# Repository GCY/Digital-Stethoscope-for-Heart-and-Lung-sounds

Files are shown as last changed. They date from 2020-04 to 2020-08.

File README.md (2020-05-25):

# Digital-Stethoscope-for-Heart-and-Lung-sounds

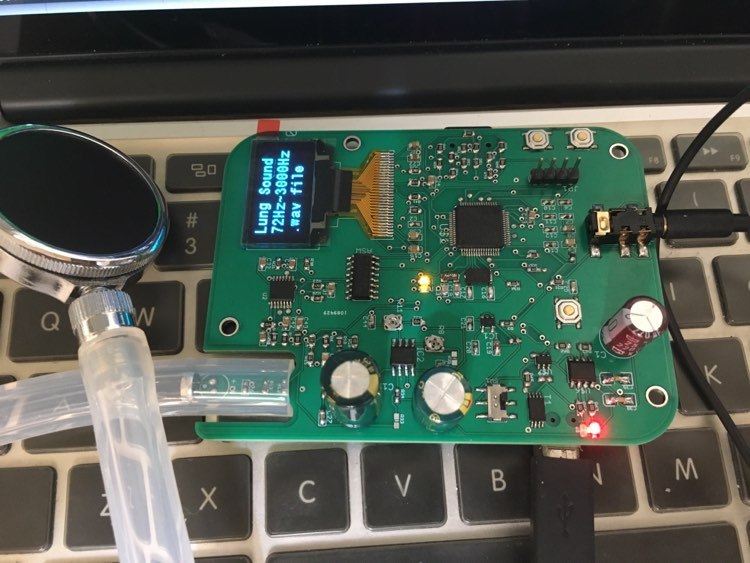
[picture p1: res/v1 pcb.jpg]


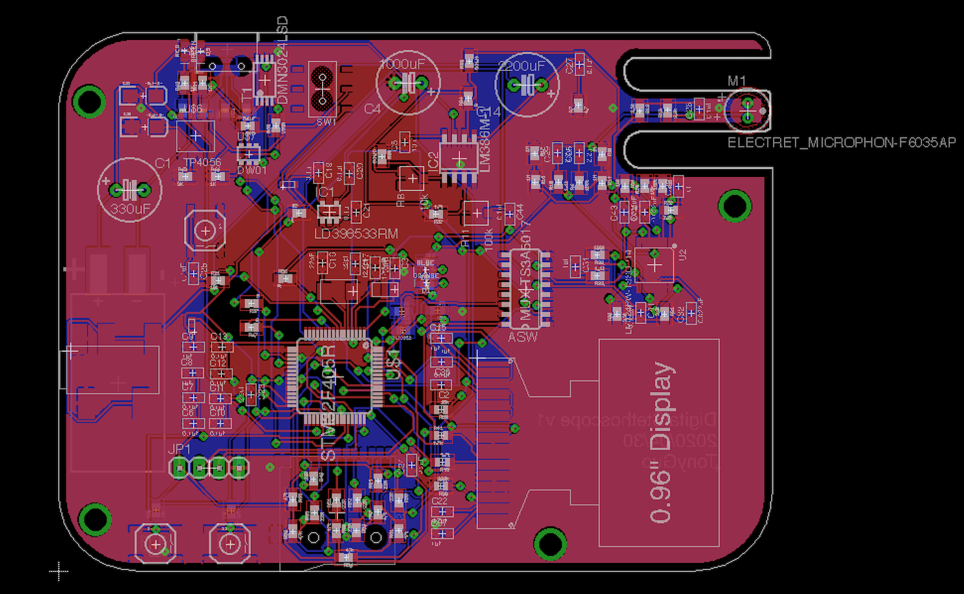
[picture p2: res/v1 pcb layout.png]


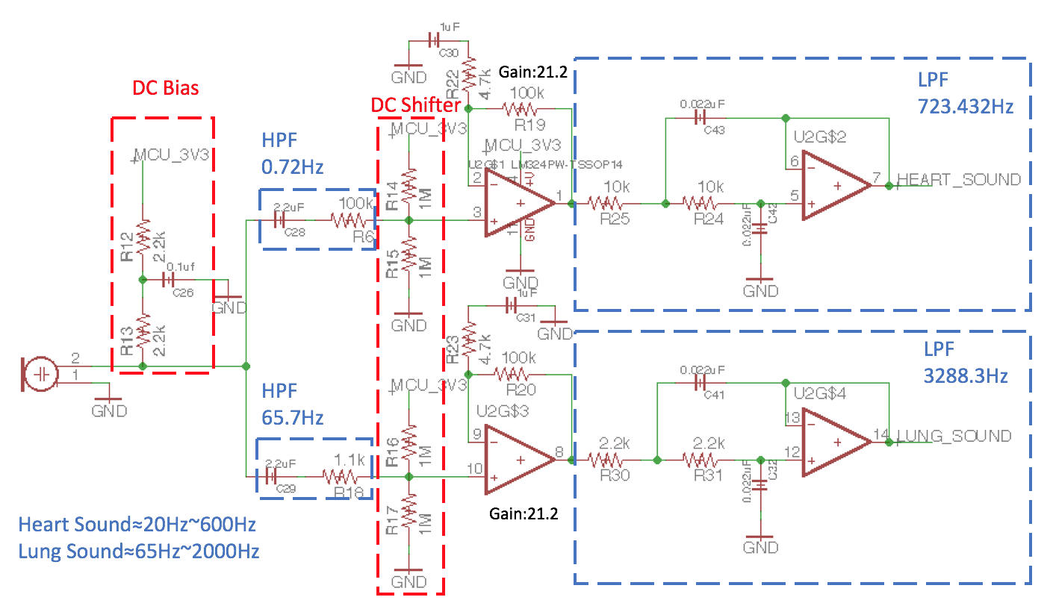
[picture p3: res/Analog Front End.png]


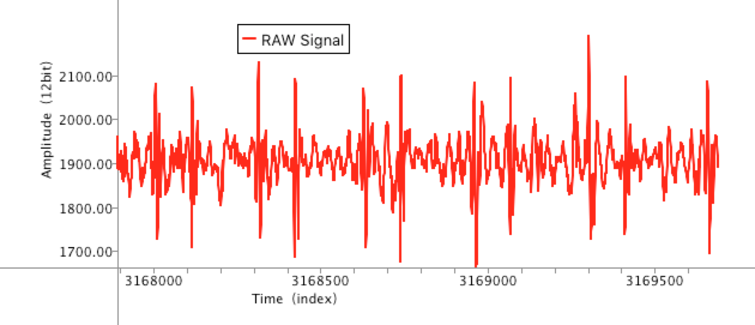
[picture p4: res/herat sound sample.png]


## Features
- [x] Headphone(3.5mm) mode for auscultation
- [ ] Heart and Lung Sounds mode switch 
- [ ] Software Filter
  - [ ] Infinite Impulse Response(IIR)
  - [ ] Finite Impulse Response(FIR)  
- [ ] Algorithm
  - [ ] Heart Sound and Lung Sound separation algorithms
- [ ] PC-Host Analysis 
  - [ ] Fast Furious Transform(FFT) amplitude spectrum
  - [ ] Mel Spectrogram
- [ ] SD card operate
  - [ ] Heart and Lung Sounds recoed .wav file to SD card
  - [ ] Replay sample of disease from SD card

## Reference
- Nersisson, R., & Noel, M. M. (2017). Heart sound and lung sound separation algorithms: a review. Journal of medical engineering & technology, 41(1), 13-21.
- Chowdhury, M. E., Khandakar, A., Alzoubi, K., Mansoor, S., M Tahir, A., Reaz, M. B. I., & Al-Emadi, N. (2019). Real-Time Smart-Digital Stethoscope System for Heart Diseases Monitoring. Sensors, 19(12), 2781.
- [How to Bias an Op-Amp](https://ocw.mit.edu/courses/media-arts-and-sciences/mas-836-sensor-technologies-for-interactive-environments-spring-2011/readings/MITMAS_836S11_read02_bias.pdf)
- [Active High Pass Filter](https://www.electronics-tutorials.ws/filter/filter_6.html) 

LICENSE
-------

MIT License

Copyright (c) 2020 Tony Guo https://github.com/GCY

Permission is hereby granted, free of charge, to any person obtaining a copy
of this software and associated documentation files (the "Software"), to deal
in the Software without restriction, including without limitation the rights
to use, copy, modify, merge, publish, distribute, sublicense, and/or sell
copies of the Software, and to permit persons to whom the Software is
furnished to do so, subject to the following conditions:

The above copyright notice and this permission notice shall be included in all
copies or substantial portions of the Software.

THE SOFTWARE IS PROVIDED "AS IS", WITHOUT WARRANTY OF ANY KIND, EXPRESS OR
IMPLIED, INCLUDING BUT NOT LIMITED TO THE WARRANTIES OF MERCHANTABILITY,
FITNESS FOR A PARTICULAR PURPOSE AND NONINFRINGEMENT. IN NO EVENT SHALL THE
AUTHORS OR COPYRIGHT HOLDERS BE LIABLE FOR ANY CLAIM, DAMAGES OR OTHER
LIABILITY, WHETHER IN AN ACTION OF CONTRACT, TORT OR OTHERWISE, ARISING FROM,
OUT OF OR IN CONNECTION WITH THE SOFTWARE OR THE USE OR OTHER DEALINGS IN THE
SOFTWARE.

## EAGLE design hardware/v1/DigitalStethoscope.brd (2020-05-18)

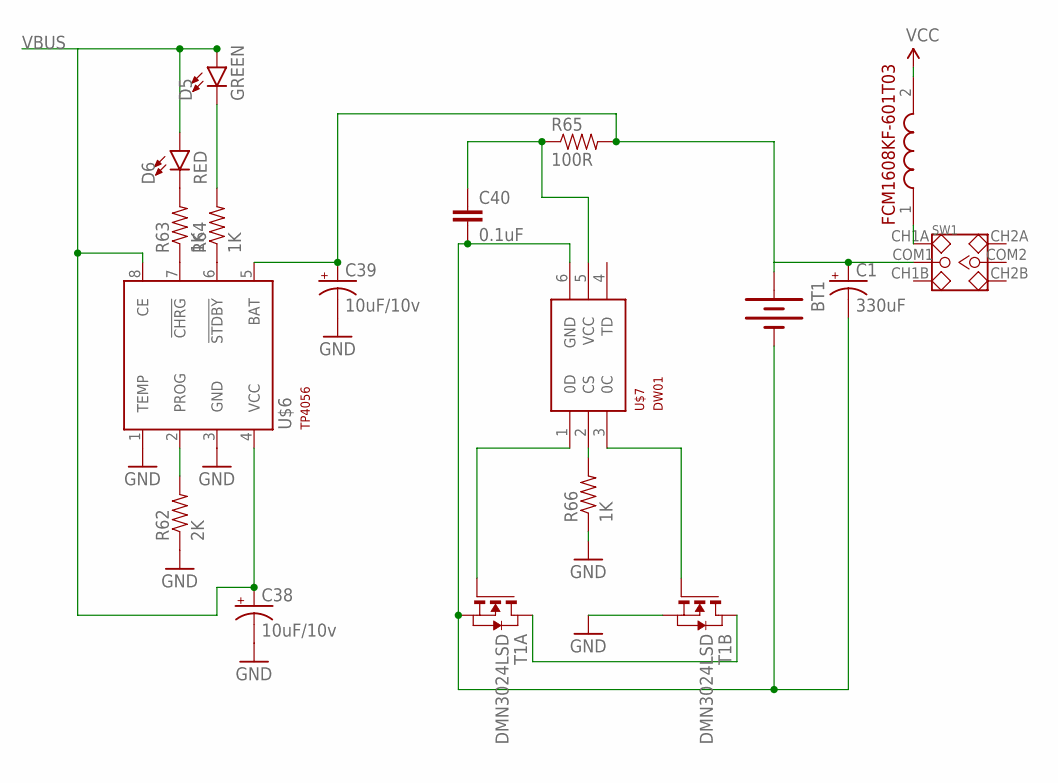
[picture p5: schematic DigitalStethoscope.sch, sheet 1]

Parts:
BT1: BATTERYLIPO-TABS; LIPO-110-TABS
C1: 330uF; E3,5-8
C38, C39: 10uF/10v; EIA3216-KIT
C40: 0.1uF; 0603-CAP
D5: GREEN; LED-0603
D6: RED; LED-0603
R62: 2K; 0603-RES
R63, R64, R66: 1K; 0603-RES
R65: 100R; 0603-RES
SW1: SMD-TOGGLE-SWITCH-2CH(2X3P-7X3.5MM); SW6-2.54-SMD-7.0X3.5X1.5MM
T1: DMN3024LSD; TSSOP-8
U$4: FCM1608KF-601T03
U$6: TP4056; SOT23-8
U$7: DW01; SOT23-6

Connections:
GND: C38.C (-), C39.C (-), R62.1, R66.1, T1.6 (S), T1.7 (S), U$6.1 (TEMP), U$6.3 (GND); also elsewhere on the board
unnamed: BT1.+, C1.+, C39.A (+), R65.2, SW1.COM1, U$6.5 (BAT)
unnamed: R62.2, U$6.2 (PROG)
unnamed: R63.1, U$6.7 (!CHRG)
unnamed: R64.1, U$6.6 (!STDBY)
unnamed: D6.C, R63.2
unnamed: D5.C, R64.2
unnamed: C40.1, R65.1, U$7.5 (VCC)
unnamed: BT1.-, C1.-, C40.2, T1.2 (S), T1.3 (S), U$7.6 (GND)
unnamed: T1.4 (G), U$7.1 (0D)
unnamed: R66.2, U$7.2 (CS)
unnamed: T1.1 (D), T1.8 (D)
unnamed: T1.5 (G), U$7.3 (0C)
unnamed: SW1.CH1A, U$4.1 (1.IN)
VBUS: C38.A (+), D5.A, D6.A, U$6.4 (VCC), U$6.8 (CE); also elsewhere on the board
VCC: U$4.2 (2.OUT); also elsewhere on the board

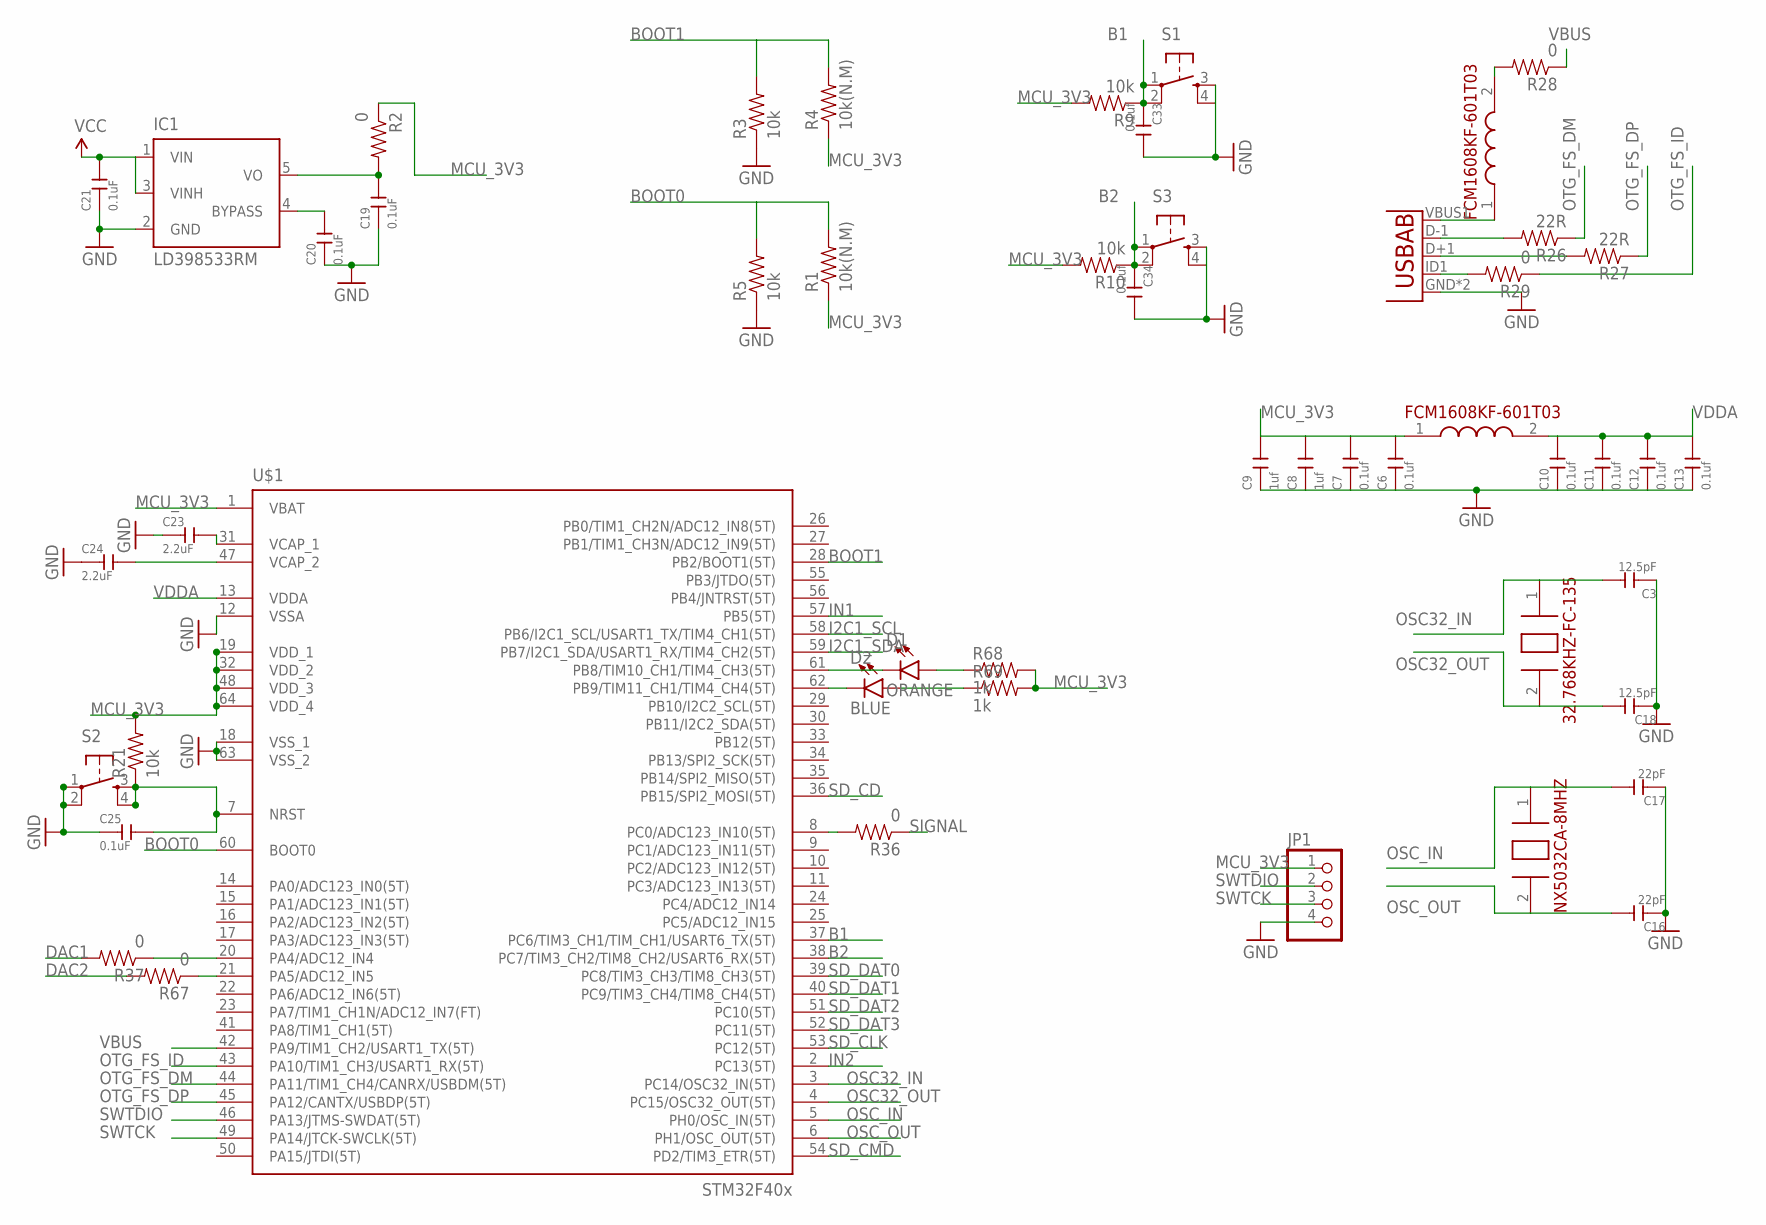
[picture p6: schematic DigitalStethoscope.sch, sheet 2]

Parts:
C3, C18: 12.5pF; C0603
C6, C7, C10, C11, C12, C13, C33, C34: 0.1uf; C0603
C8, C9: 1uf; C0603
C16, C17: 22pF; C0603
C19, C20, C21, C25: 0.1uF; C0603
C23, C24: 2.2uF; C0603
D1: ORANGE; LED-0603
D2: BLUE; LED-0603
IC1: LD398533RM; SOT23-5L
JP1: PINHD-1X4; 1X04
R1, R4: 10k(N.M); 0603
R2, R28, R29, R36, R37, R67: 0; 0603-RES
R3, R5, R9, R10: 10k; 0603
R21: 10k; 0603-RES
R26, R27: 22R; 0603-RES
R68, R69: 1k; 0603-RES
S1, S2, S3: TAC_SWITCHSMD; TACTILE_SWITCH_SMD
U4: USB""; USB-MICRO-SMD
U$1: STM32F405R; TQFP64
U$2: 32.768KHZ-FC-135
U$3, U$5: FCM1608KF-601T03
U$8: NX5032CA-8MHZ

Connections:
B1: C33.1, R9.1, S1.1, S1.2, U$1.37 (PC6/TIM3_CH1/TIM_CH1/USART6_TX(5T))
B2: C34.1, R10.1, S3.1, S3.2, U$1.38 (PC7/TIM3_CH2/TIM8_CH2/USART6_RX(5T))
BOOT0: R1.2, R5.2, U$1.60 (BOOT0)
BOOT1: R3.2, R4.2, U$1.28 (PB2/BOOT1(5T))
DAC1: R37.2; also elsewhere on the board
DAC2: R67.2; also elsewhere on the board
GND: C3.1, C6.1, C7.1, C8.1, C9.1, C10.1, C11.1, C12.1, C13.1, C16.1, C17.1, C18.1, C19.1, C20.1, C21.1, C23.1, C24.1, C25.1, C33.2, C34.2, IC1.2 (GND), JP1.4, R3.1, R5.1, S1.3, S1.4, S2.1, S2.2, S3.3, S3.4, U4.GND, U4.GND1 (GND), U$1.12 (VSSA), U$1.18 (VSS_1), U$1.63 (VSS_2); also elsewhere on the board
I2C1_SCL: U$1.58 (PB6/I2C1_SCL/USART1_TX/TIM4_CH1(5T)); also elsewhere on the board
I2C1_SDA: U$1.59 (PB7/I2C1_SDA/USART1_RX/TIM4_CH2(5T)); also elsewhere on the board
IN1: U$1.57 (PB5(5T)); also elsewhere on the board
IN2: U$1.2 (PC13(5T)); also elsewhere on the board
MCU_3V3: C6.2, C7.2, C8.2, C9.2, JP1.1, R1.1, R2.1, R4.1, R9.2, R10.2, R21.2, R68.2, R69.2, U$1.1 (VBAT), U$1.19 (VDD_1), U$1.32 (VDD_2), U$1.48 (VDD_3), U$1.64 (VDD_4), U$3.1 (1.IN); also elsewhere on the board
unnamed: C20.2, IC1.4 (BYPASS)
unnamed: R36.2, U$1.8 (PC0/ADC123_IN10(5T))
unnamed: R26.2, U4.D-1 (D-)
unnamed: C23.2, U$1.31 (VCAP_1)
unnamed: C24.2, U$1.47 (VCAP_2)
unnamed: R37.1, U$1.20 (PA4/ADC12_IN4)
unnamed: C25.2, R21.1, S2.3, S2.4, U$1.7 (NRST)
unnamed: C19.2, IC1.5 (VO), R2.2
unnamed: R27.2, U4.D+1 (D+)
unnamed: U4.VBUS1 (VBUS), U$5.1 (1.IN)
unnamed: R29.2, U4.ID1 (USBID)
unnamed: R28.2, U$5.2 (2.OUT)
unnamed: R67.1, U$1.21 (PA5/ADC12_IN5)
unnamed: D2.C, U$1.62 (PB9/TIM11_CH1/TIM4_CH4(5T))
unnamed: D1.C, U$1.61 (PB8/TIM10_CH1/TIM4_CH3(5T))
unnamed: D1.A, R68.1
unnamed: D2.A, R69.1
OSC32_IN: C3.2, U$1.3 (PC14/OSC32_IN(5T)), U$2.1 (1.XIN)
OSC32_OUT: C18.2, U$1.4 (PC15/OSC32_OUT(5T)), U$2.2 (2.XIN)
OSC_IN: C17.2, U$1.5 (PH0/OSC_IN(5T)), U$8.1 (1.XIN)
OSC_OUT: C16.2, U$1.6 (PH1/OSC_OUT(5T)), U$8.2 (2.XOUT)
OTG_FS_DM: R26.1, U$1.44 (PA11/TIM1_CH4/CANRX/USBDM(5T))
OTG_FS_DP: R27.1, U$1.45 (PA12/CANTX/USBDP(5T))
OTG_FS_ID: R29.1, U$1.43 (PA10/TIM1_CH3/USART1_RX(5T))
SD_CD: U$1.36 (PB15/SPI2_MOSI(5T)); also elsewhere on the board
SD_CLK: U$1.53 (PC12(5T)); also elsewhere on the board
SD_CMD: U$1.54 (PD2/TIM3_ETR(5T)); also elsewhere on the board
SD_DAT0: U$1.39 (PC8/TIM3_CH3/TIM8_CH3(5T)); also elsewhere on the board
SD_DAT1: U$1.40 (PC9/TIM3_CH4/TIM8_CH4(5T)); also elsewhere on the board
SD_DAT2: U$1.51 (PC10(5T)); also elsewhere on the board
SD_DAT3: U$1.52 (PC11(5T)); also elsewhere on the board
SIGNAL: R36.1; also elsewhere on the board
SWTCK: JP1.3, U$1.49 (PA14/JTCK-SWCLK(5T))
SWTDIO: JP1.2, U$1.46 (PA13/JTMS-SWDAT(5T))
VBUS: R28.1, U$1.42 (PA9/TIM1_CH2/USART1_TX(5T)); also elsewhere on the board
VCC: C21.2, IC1.1 (VIN), IC1.3 (VINH); also elsewhere on the board
VDDA: C10.2, C11.2, C12.2, C13.2, U$1.13 (VDDA), U$3.2 (2.OUT)

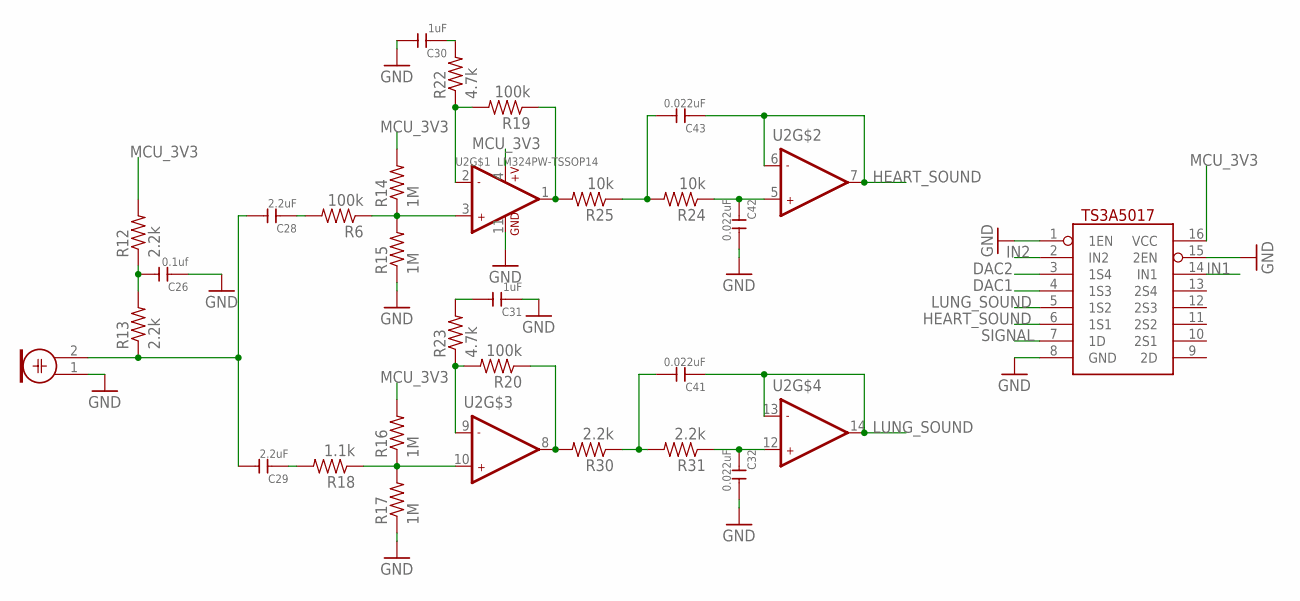
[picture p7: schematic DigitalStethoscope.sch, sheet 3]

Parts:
ASW: MUX-TS3A5017; SO16
C26: 0.1uf; C0603
C28, C29: 2.2uF; C0603
C30, C31: 1uF; C0603
C32, C41, C42, C43: 0.022uF; C0603
M1: ELECTRET_MICROPHON-F6035AP; F6035AP
R6, R19, R20: 100k; 0603-RES
R12, R13, R30, R31: 2.2k; 0603-RES
R14, R15, R16, R17: 1M; 0603-RES
R18: 1.1k; 0603-RES
R22, R23: 4.7k; 0603-RES
R24, R25: 10k; 0603-RES
U2: LM324PW-TSSOP14; TSSOP14-0.65-5X4.4MM

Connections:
DAC1: ASW.4 (1S3); also elsewhere on the board
DAC2: ASW.3 (1S4); also elsewhere on the board
GND: ASW.1 (1EN), ASW.8 (GND), ASW.15 (2EN), C26.1, C30.2, C31.1, C32.2, C42.2, M1.1, R15.1, R17.1, U2.11 (GND); also elsewhere on the board
HEART_SOUND: ASW.6 (1S1), C43.1, U2.6 (-IN2), U2.7 (OUT2)
IN1: ASW.14 (IN1); also elsewhere on the board
IN2: ASW.2 (IN2); also elsewhere on the board
LUNG_SOUND: ASW.5 (1S2), C41.1, U2.13 (-IN2), U2.14 (OUT2)
MCU_3V3: ASW.16 (VCC), R12.2, R14.2, R16.2, U2.4 (+V); also elsewhere on the board
unnamed: C26.2, R12.1, R13.2
unnamed: C28.2, C29.2, M1.2, R13.1
unnamed: R6.1, R14.1, R15.2, U2.3 (+IN1)
unnamed: R16.1, R17.2, R18.1, U2.10 (+IN2)
unnamed: C29.1, R18.2
unnamed: C28.1, R6.2
unnamed: R19.2, R22.1, U2.2 (-IN1)
unnamed: R19.1, R25.2, U2.1 (OUT1)
unnamed: C30.1, R22.2
unnamed: R20.2, R23.1, U2.9 (-IN2)
unnamed: R20.1, R30.2, U2.8 (OUT2)
unnamed: C31.2, R23.2
unnamed: C43.2, R24.2, R25.1
unnamed: C42.1, R24.1, U2.5 (+IN2)
unnamed: C41.2, R30.1, R31.2
unnamed: C32.1, R31.1, U2.12 (+IN2)
SIGNAL: ASW.7 (1D); also elsewhere on the board

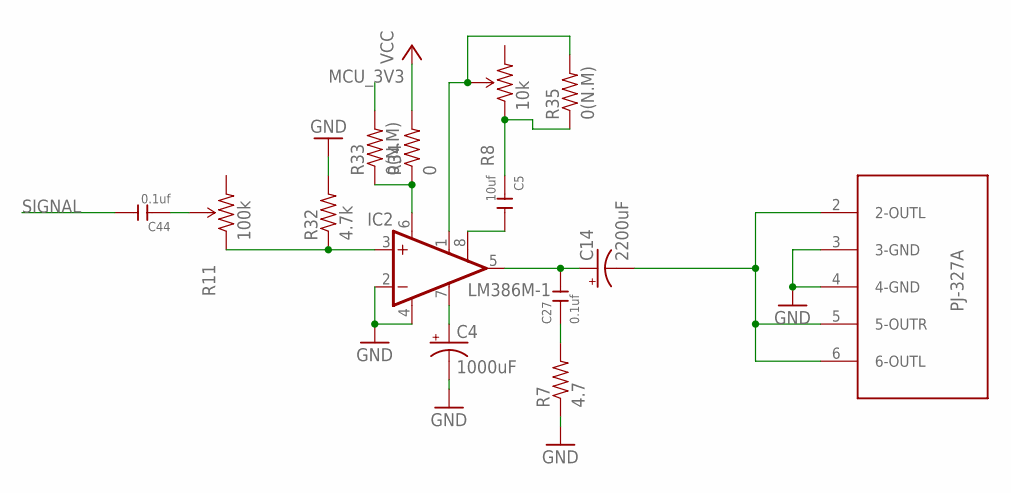
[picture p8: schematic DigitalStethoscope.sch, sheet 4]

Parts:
C4: 1000uF; E3,5-8
C5: 10uf; C0603
C14: 2200uF; E3,5-8
C27, C44: 0.1uf; C0603
IC2: LM386M-1; SO08
R7: 4.7; 0603-RES
R8: 10k; TRIMPOT_TC33
R11: 100k; TRIMPOT_TC33
R32: 4.7k; 0603-RES
R33, R35: 0(N.M); 0603-RES
R34: 0; 0603-RES
U$9: PJ-327A

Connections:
GND: C4.-, IC2.2 (-IN), IC2.4 (GND), R7.1, R32.2, U$9.3 (3-GND), U$9.4 (4-GND); also elsewhere on the board
MCU_3V3: R33.2; also elsewhere on the board
unnamed: IC2.3 (+IN), R11.1 (CCW), R32.1
unnamed: C44.1, R11.2 (WIPER)
unnamed: C4.+, IC2.7 (BYPASS)
unnamed: C14.+, C27.2, IC2.5 (OUT)
unnamed: C27.1, R7.2
unnamed: C5.2, IC2.8 (GAIN)
unnamed: C5.1, R8.1 (CCW), R35.1
unnamed: IC2.1 (GAIN), R8.2 (WIPER), R35.2
unnamed: C14.-, U$9.2 (2-OUTL), U$9.5 (5-OUTR), U$9.6 (6-OUTL)
unnamed: IC2.6 (VS), R33.1, R34.1
SIGNAL: C44.2; also elsewhere on the board
VCC: R34.2; also elsewhere on the board

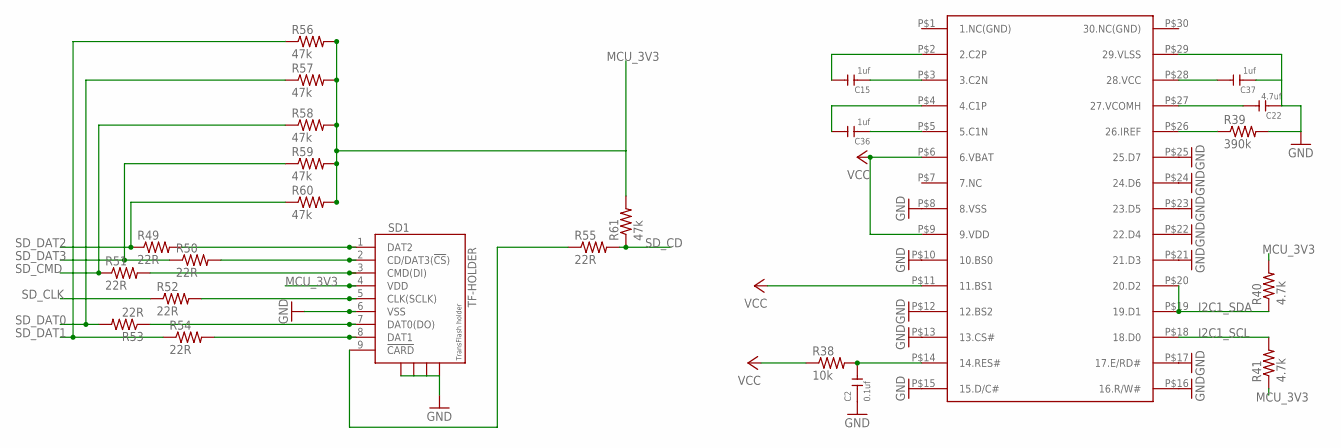
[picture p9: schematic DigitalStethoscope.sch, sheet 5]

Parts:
C2: 0.1uf; C0603
C15, C36, C37: 1uf; C0603
C22: 4.7uf; C0603
R38: 10k; 0603
R39: 390k; 0603
R40, R41: 4.7k; 0603
R49, R50, R51, R52, R53, R54, R55: 22R; 0603-RES
R56, R57, R58, R59, R60, R61: 47k; 0603-RES
SD1: TF-HOLDER; TF-PULL
U$18: ER-OLED0.96

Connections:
GND: C2.1, C22.1, C37.1, R39.2, SD1.6 (VSS), SD1.S1, SD1.S2, SD1.S3, SD1.S4, U$18.P$8 (8.VSS), U$18.P$10 (10.BS0), U$18.P$12 (12.BS2), U$18.P$13 (13.CS#), U$18.P$15 (15.D/C#), U$18.P$16 (16.R/W#), U$18.P$17 (17.E/RD#), U$18.P$21 (21.D3), U$18.P$22 (22.D4), U$18.P$23 (23.D5), U$18.P$24 (24.D6), U$18.P$25 (25.D7), U$18.P$29 (29.VLSS); also elsewhere on the board
I2C1_SCL: R41.2, U$18.P$18 (18.D0); also elsewhere on the board
I2C1_SDA: R40.1, U$18.P$19 (19.D1), U$18.P$20 (20.D2); also elsewhere on the board
MCU_3V3: R40.2, R41.1, R56.2, R57.2, R58.2, R59.2, R60.2, R61.2, SD1.4 (VDD); also elsewhere on the board
unnamed: R49.2, SD1.1 (DAT2)
unnamed: C2.2, R38.2, U$18.P$14 (14.RES#)
unnamed: C15.1, U$18.P$3 (3.C2N)
unnamed: C36.1, U$18.P$5 (5.C1N)
unnamed: C15.2, U$18.P$2 (2.C2P)
unnamed: C36.2, U$18.P$4 (4.C1P)
unnamed: R39.1, U$18.P$26 (26.IREF)
unnamed: C22.2, U$18.P$27 (27.VCOMH)
unnamed: C37.2, U$18.P$28 (28.VCC)
unnamed: R50.2, SD1.2 (CD/DAT3(!CS!))
unnamed: R51.2, SD1.3 (CMD(DI))
unnamed: R52.2, SD1.5 (CLK(SCLK))
unnamed: R53.1, SD1.7 (DAT0(DO))
unnamed: R54.2, SD1.8 (DAT1)
unnamed: R55.1, SD1.9 (!CARD)
SD_CD: R55.2, R61.1; also elsewhere on the board
SD_CLK: R52.1; also elsewhere on the board
SD_CMD: R51.1, R58.1; also elsewhere on the board
SD_DAT0: R53.2, R57.1; also elsewhere on the board
SD_DAT1: R54.1, R56.1; also elsewhere on the board
SD_DAT2: R49.1, R60.1; also elsewhere on the board
SD_DAT3: R50.1, R59.1; also elsewhere on the board
VCC: R38.1, U$18.P$6 (6.VBAT), U$18.P$9 (9.VDD), U$18.P$11 (11.BS1); also elsewhere on the board

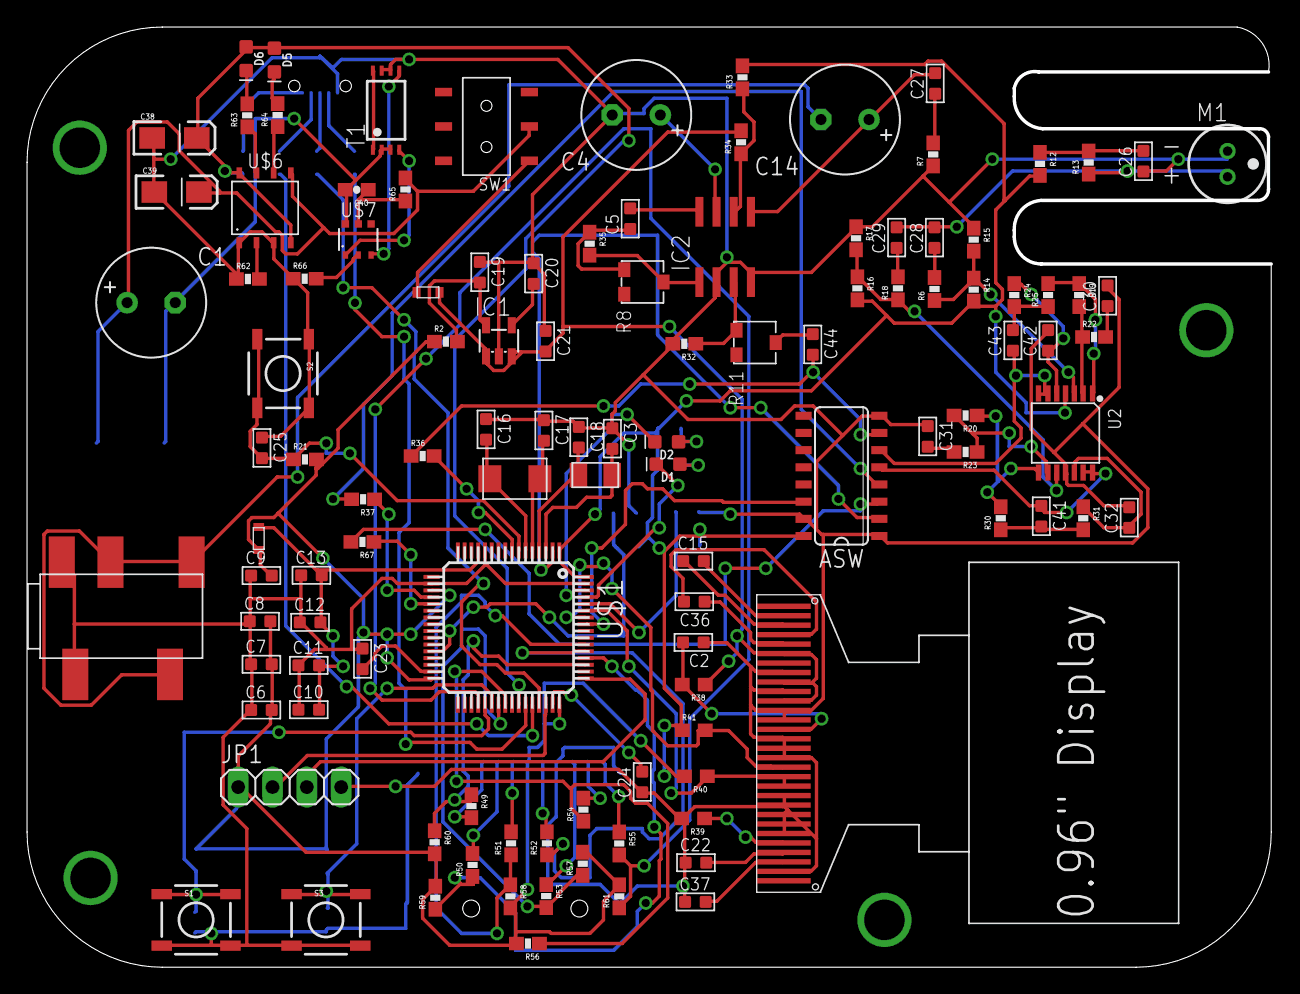
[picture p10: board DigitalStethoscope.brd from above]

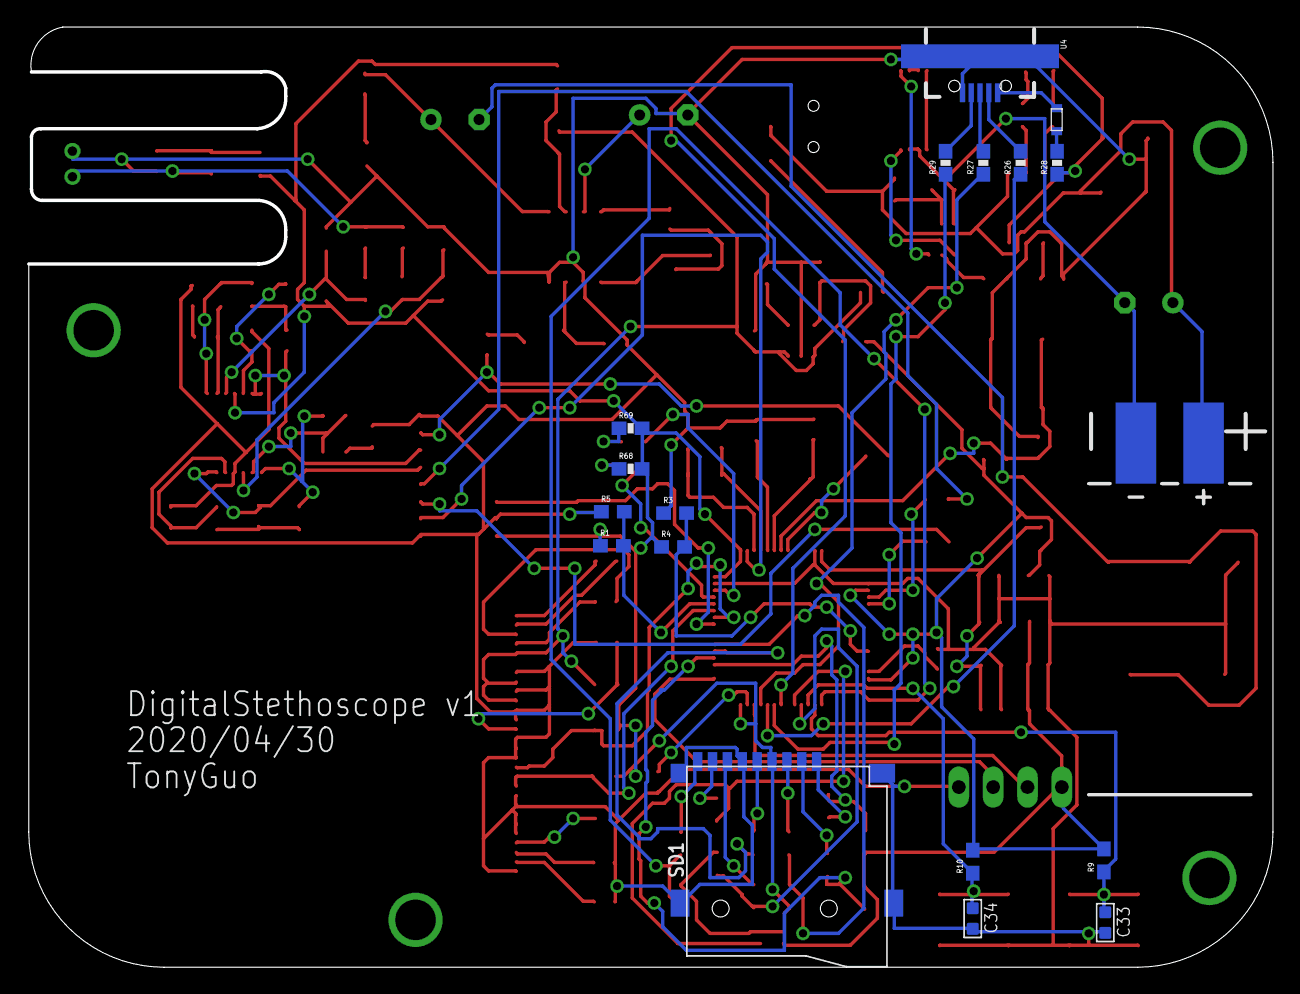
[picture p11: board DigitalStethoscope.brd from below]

Board: 2 copper layers, 92.0 x 69.5 mm, 133 parts (18 on the bottom side), 105 nets.

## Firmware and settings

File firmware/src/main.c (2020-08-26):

#include <stdio.h>
#include <stdarg.h>
#include <stdbool.h>

#include <stm32f4xx.h>
#include <stm32f4xx_gpio.h>
#include <stm32f4xx_usart.h>
#include <stm32f4xx_exti.h>
#include <stm32f4xx_i2c.h>
#include <stm32f4xx_adc.h>
#include <stm32f4xx_rcc.h>
#include <stm32f4xx_dma.h>
#include <stm32f4xx_rtc.h>
#include <stm32f4xx_tim.h>

#include "./FATFS/ff.h"

#include "define.h"

#include "I2C.h"
#include "SSD1306.h"

#include "FIR.h"
#include "adaptive_algorithm.h"

#include "adc.h"

#include "tiny_printf.h"

#include "./usb_cdc_device/usbd_audio_core.h"
#include "./usb_cdc_device/usbd_usr.h"
#include "./usb_cdc_device/usbd_desc.h"
#include "./usb_cdc_device/usbd_audio_core.h"
#include "./usb_cdc_device/waverecorder.h"

#define __FPU_PRESENT
#define __FPU_USED

__ALIGN_BEGIN USB_OTG_CORE_HANDLE  USB_OTG_dev __ALIGN_END;

const uint32_t SECOND = 1000000;

const uint16_t PWM_Freq = 1000;

volatile uint32_t TimingDelay;

volatile uint32_t micros = 20000000;

uint32_t last_update;
uint32_t last_screen_update;

volatile uint8_t button_flag = 0;


const unsigned int taps = 19;
//100hz 0.7Hz~8.9Hz
float coeff1[19] = {-0.043047,-0.048389,-0.042549,-0.023677,0.0073069,0.046611,0.088179,0.12489,0.15008,0.15905,0.15008,0.12489,0.088179,0.046611,0.0073069,-0.023677,-0.042549,-0.048389,-0.043047};
// 100Hz 0.5Hz low pass
float coeff2[19] = {0.050186,0.050989,0.051705,0.052331,0.052864,0.053303,0.053646,0.053892,0.05404,0.054089,0.05404,0.053892,0.053646,0.053303,0.052864,0.052331,0.051705,0.050989,0.050186};
float buffer1[19];
unsigned offset1;
float buffer2[19];
unsigned offset2;

FIRInfo info1;
FIRInfo info2;

void Delay(__IO uint32_t nTime)
{
   TimingDelay = nTime;
   while(TimingDelay){
   }
}

void SysTick_Handler(void)
{
   if(TimingDelay){
      --TimingDelay;
   }
   ++micros;
}

void Init_LED()
{
   //Enable the GPIOD Clock
   RCC_AHB1PeriphClockCmd(RCC_AHB1Periph_GPIOB,ENABLE);


   // GPIOD Configuration
   GPIO_InitTypeDef GPIO_InitStruct;
   GPIO_InitStruct.GPIO_Pin = GPIO_Pin_8 | GPIO_Pin_9;
   GPIO_InitStruct.GPIO_Mode = GPIO_Mode_OUT;
   GPIO_InitStruct.GPIO_Speed = GPIO_Speed_50MHz;
   GPIO_InitStruct.GPIO_OType = GPIO_OType_PP;
   GPIO_InitStruct.GPIO_PuPd = GPIO_PuPd_UP;

   GPIO_SetBits(GPIOB, GPIO_Pin_8);
   GPIO_SetBits(GPIOB, GPIO_Pin_9);
   GPIO_Init(GPIOB, &GPIO_InitStruct);   
}

void Init_AnalogSwitch()
{
   //Enable the GPIOD Clock
   RCC_AHB1PeriphClockCmd(RCC_AHB1Periph_GPIOB,ENABLE);


   // GPIOD Configuration
   GPIO_InitTypeDef GPIO_InitStruct;
   GPIO_InitStruct.GPIO_Pin = GPIO_Pin_5;
   GPIO_InitStruct.GPIO_Mode = GPIO_Mode_OUT;
   GPIO_InitStruct.GPIO_Speed = GPIO_Speed_50MHz;
   GPIO_InitStruct.GPIO_OType = GPIO_OType_PP;
   GPIO_InitStruct.GPIO_PuPd = GPIO_PuPd_UP;

   GPIO_SetBits(GPIOB, GPIO_Pin_5);
   GPIO_Init(GPIOB, &GPIO_InitStruct);   



   RCC_AHB1PeriphClockCmd(RCC_AHB1Periph_GPIOC,ENABLE);


   // GPIOD Configuration
   GPIO_InitStruct.GPIO_Pin = GPIO_Pin_13;
   GPIO_InitStruct.GPIO_Mode = GPIO_Mode_OUT;
   GPIO_InitStruct.GPIO_Speed = GPIO_Speed_50MHz;
   GPIO_InitStruct.GPIO_OType = GPIO_OType_PP;
   GPIO_InitStruct.GPIO_PuPd = GPIO_PuPd_UP;

   GPIO_ResetBits(GPIOC, GPIO_Pin_13);
   GPIO_Init(GPIOC, &GPIO_InitStruct);   

}


void EXTILine6_Config(void)
{
   EXTI_InitTypeDef   EXTI_InitStructure;
   GPIO_InitTypeDef   GPIO_InitStructure;
   NVIC_InitTypeDef   NVIC_InitStructure;

   /* Enable GPIOB clock */
   RCC_AHB1PeriphClockCmd(RCC_AHB1Periph_GPIOC, ENABLE);
   /* Enable SYSCFG clock */
   RCC_APB2PeriphClockCmd(RCC_APB2Periph_SYSCFG, ENABLE);

   /* Configure PB0 pin as input floating */
   GPIO_InitStructure.GPIO_Mode = GPIO_Mode_IN;
   GPIO_InitStructure.GPIO_PuPd = GPIO_PuPd_NOPULL;
   GPIO_InitStructure.GPIO_Pin = GPIO_Pin_6;
   GPIO_Init(GPIOC, &GPIO_InitStructure);

   /* Connect EXTI Line0 to PB0 pin */
   SYSCFG_EXTILineConfig(EXTI_PortSourceGPIOC, EXTI_PinSource6);

   /* Configure EXTI Line0 */
   EXTI_InitStructure.EXTI_Line = EXTI_Line6;
   EXTI_InitStructure.EXTI_Mode = EXTI_Mode_Interrupt;
   EXTI_InitStructure.EXTI_Trigger = EXTI_Trigger_Rising_Falling;  
   EXTI_InitStructure.EXTI_LineCmd = ENABLE;
   EXTI_Init(&EXTI_InitStructure);

   /* Enable and set EXTI Line0 Interrupt to the lowest priority */
   NVIC_InitStructure.NVIC_IRQChannel = EXTI9_5_IRQn;
   NVIC_InitStructure.NVIC_IRQChannelPreemptionPriority = 1;
   NVIC_InitStructure.NVIC_IRQChannelSubPriority = 0;
   NVIC_InitStructure.NVIC_IRQChannelCmd = ENABLE;
   NVIC_Init(&NVIC_InitStructure);
}

void EXTILine7_Config(void)
{
   EXTI_InitTypeDef   EXTI_InitStructure;
   GPIO_InitTypeDef   GPIO_InitStructure;
   NVIC_InitTypeDef   NVIC_InitStructure;

   /* Enable GPIOB clock */
   RCC_AHB1PeriphClockCmd(RCC_AHB1Periph_GPIOC, ENABLE);
   /* Enable SYSCFG clock */
   RCC_APB2PeriphClockCmd(RCC_APB2Periph_SYSCFG, ENABLE);

   /* Configure PB0 pin as input floating */
   GPIO_InitStructure.GPIO_Mode = GPIO_Mode_IN;
   GPIO_InitStructure.GPIO_PuPd = GPIO_PuPd_NOPULL;
   GPIO_InitStructure.GPIO_Pin = GPIO_Pin_7;
   GPIO_Init(GPIOC, &GPIO_InitStructure);

   /* Connect EXTI Line0 to PB0 pin */
   SYSCFG_EXTILineConfig(EXTI_PortSourceGPIOC, EXTI_PinSource7);

   /* Configure EXTI Line0 */
   EXTI_InitStructure.EXTI_Line = EXTI_Line7;
   EXTI_InitStructure.EXTI_Mode = EXTI_Mode_Interrupt;
   EXTI_InitStructure.EXTI_Trigger = EXTI_Trigger_Rising_Falling;  
   EXTI_InitStructure.EXTI_LineCmd = ENABLE;
   EXTI_Init(&EXTI_InitStructure);

   /* Enable and set EXTI Line0 Interrupt to the lowest priority */
   NVIC_InitStructure.NVIC_IRQChannel = EXTI9_5_IRQn;
   NVIC_InitStructure.NVIC_IRQChannelPreemptionPriority = 1;
   NVIC_InitStructure.NVIC_IRQChannelSubPriority = 1;
   NVIC_InitStructure.NVIC_IRQChannelCmd = ENABLE;
   NVIC_Init(&NVIC_InitStructure);
}

void Init_Peripheral()
{
   USBD_Init(&USB_OTG_dev,      
	 USB_OTG_FS_CORE_ID,
	 &USR_desc, 
	 &AUDIO_cb, 
	 &USR_cb);
   Delay(10000);

   Init_LED();
   EXTILine6_Config();
   EXTILine7_Config();
   Delay(10000);

   Init_AnalogSwitch();
   Delay(10000);

   Init_I2C3();
   Init_SSD1306();
   Delay(10000);

   //Init_ADC(); //ADC3 Pooling
   ADC_4_Channel_Init(); // DMA + TIMER + FIFO, 1000Hz sampling rate
   Delay(10000);

   /* if external clock is work */
   __IO uint32_t HSEStatus = 0;
   HSEStatus = RCC->CR & RCC_CR_HSERDY;
   if(HSEStatus){
      GPIO_ResetBits(GPIOB, GPIO_Pin_8);
   }
   else{
      GPIO_SetBits(GPIOB, GPIO_Pin_8);
   }     
}

////////////////
long map(long x, long in_min, long in_max, long out_min, long out_max){
   return (x - in_min) * (out_max - out_min) / (in_max - in_min) + out_min;
}


int main(void)
{
   if(SysTick_Config(SystemCoreClock / 1000 / 1000)){
      while(1){}
   }

   Init_Peripheral();

   SSD1306_Fill(0x00);
   SSD1306_UpdateScreen();
   Delay(SECOND);
   SSD1306_Fill(0xFF);
   SSD1306_UpdateScreen();
   Delay(SECOND);
   SSD1306_Fill(0x00);
   SSD1306_UpdateScreen();  
   Delay(SECOND);   

   SSD1306_GotoXY(3, 4);
   SSD1306_Puts("Stethoscope", &Font_11x18, 0xFF);
   SSD1306_GotoXY(3, 25);
   SSD1306_Puts("20200515", &Font_11x18, 0xFF);
   SSD1306_GotoXY(3, 45);
   SSD1306_Puts("TonyGUO", &Font_11x18, 0xFF);
   SSD1306_UpdateScreen();  
   Delay(SECOND);
   SSD1306_Fill(0x00);
   SSD1306_UpdateScreen();

   SSD1306_GotoXY(3, 4);
   SSD1306_Puts("Lung Sound", &Font_11x18, 0xFF);
   SSD1306_GotoXY(3, 25);
   SSD1306_Puts("72Hz~3000Hz", &Font_11x18, 0xFF);
   SSD1306_GotoXY(3, 45);
   SSD1306_Puts(".wav file", &Font_11x18, 0xFF);
   SSD1306_UpdateScreen();     



   last_update = micros;
   last_screen_update = micros;

   FATFS fs;
   FIL fnew;	
   FRESULT res_sd; 
   UINT fnum;   

   res_sd = f_mount(&fs,"0:",1);
   if(res_sd == FR_NO_FILESYSTEM){
      res_sd=f_mkfs("0:",0,0);							

      if(res_sd == FR_OK){
	 res_sd = f_mount(NULL,"0:",1);					
	 res_sd = f_mount(&fs,"0:",1);
      }
      else{
	 GPIO_ResetBits(GPIOB, GPIO_Pin_9);
      }
   }

   res_sd = f_open(&fnew, "0:FatFs 20200515.csv",FA_CREATE_ALWAYS | FA_WRITE );
   BYTE WriteBuffer[255] = {0};
   sprintf(WriteBuffer,"%d,%d,%d\r\n",micros,12345,54321);
   res_sd=f_write(&fnew,WriteBuffer,strlen(WriteBuffer),&fnum);

   f_close(&fnew); 


   SSD1306_Fill(0x00);
   SSD1306_UpdateScreen();  
   Delay(SECOND); 

   while(1){
      /*
	 if(button_flag == 0){
	 SSD1306_Fill(0xFF);
	 SSD1306_UpdateScreen();
	 Delay(SECOND);
	 SSD1306_Fill(0x00);
	 SSD1306_UpdateScreen();  
	 Delay(SECOND); 
	 }      
	 else if(button_flag == 6){
	 SSD1306_Fill(0x00);
	 SSD1306_UpdateScreen(); 
	 SSD1306_GotoXY(3, 25);
	 SSD1306_Puts("PC6", &Font_11x18, 0xFF);
	 SSD1306_UpdateScreen();  

	 }
	 else if(button_flag == 7){
	 SSD1306_Fill(0x00);
	 SSD1306_UpdateScreen(); 
	 SSD1306_GotoXY(3, 25);
	 SSD1306_Puts("PC7", &Font_11x18, 0xFF);
	 SSD1306_UpdateScreen();  

	 }
	 */
   }

   return(0); // System will implode
}    

void EXTI9_5_IRQHandler(void)
{
   button_flag = 6;
   if(EXTI_GetITStatus(EXTI_Line6) != RESET){
      button_flag = 6;
      EXTI_ClearITPendingBit(EXTI_Line6);
      EXTI_ClearFlag(EXTI_Line6);    
   } 
   if(EXTI_GetITStatus(EXTI_Line7) != RESET){
      button_flag = 7;
      EXTI_ClearITPendingBit(EXTI_Line7);
      EXTI_ClearFlag(EXTI_Line7);    
   }

   EXTI_ClearITPendingBit(EXTI9_5_IRQn);

}

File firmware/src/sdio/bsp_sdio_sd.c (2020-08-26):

/**
  ******************************************************************************
  * @file    stm324x9i_eval_sdio_sd.c
  * @author  MCD Application Team
  * @version V1.0.3
  * @date    13-November-2013
  * @brief   This file provides a set of functions needed to manage the SDIO SD 
  *          Card memory mounted on STM324x9I-EVAL evaluation board. 
  *          
  *            
  *  @verbatim
  *
  *          ===================================================================
  *                                   How to use this driver
  *          ===================================================================
  *          It implements a high level communication layer for read and write 
  *          from/to this memory. The needed STM32 hardware resources (SDIO and 
  *          GPIO) are defined in stm324x9i_eval.h file, and the initialization is 
  *          performed in SD_LowLevel_Init() function declared in stm324x9i_eval.c 
  *          file.
  *          You can easily tailor this driver to any other development board, 
  *          by just adapting the defines for hardware resources and 
  *          SD_LowLevel_Init() function.
  *
  *          A - SD Card Initialization and configuration
  *          ============================================    
  *            - To initialize the SD Card, use the SD_Init() function.  It 
  *              Initializes the SD Card and put it into StandBy State (Ready 
  *              for data transfer). This function provides the following operations:
  *
  *              1 - Apply the SD Card initialization process at 400KHz and check
  *                  the SD Card type (Standard Capacity or High Capacity). You 
  *                  can change or adapt this frequency by adjusting the 
  *                  "SDIO_INIT_CLK_DIV" define inside the stm324x9i_eval.h file. 
  *                  The SD Card frequency (SDIO_CK) is computed as follows:
  *
  *                     +---------------------------------------------+
  *                     | SDIO_CK = SDIOCLK / (SDIO_INIT_CLK_DIV + 2) |
  *                     +---------------------------------------------+
  *
  *                  In initialization mode and according to the SD Card standard, 
  *                  make sure that the SDIO_CK frequency doesn't exceed 400KHz.
  *
  *              2 - Get the SD CID and CSD data. All these information are
  *                  managed by the SDCardInfo structure. This structure provides
  *                  also ready computed SD Card capacity and Block size.   
  *
  *              3 - Configure the SD Card Data transfer frequency. By Default,
  *                  the card transfer frequency is set to 24MHz. You can change
  *                  or adapt this frequency by adjusting the "SDIO_TRANSFER_CLK_DIV" 
  *                  define inside the stm324x9i_eval.h file.
  *                  The SD Card frequency (SDIO_CK) is computed as follows:
  *
  *                     +---------------------------------------------+
  *                     | SDIO_CK = SDIOCLK / (SDIO_INIT_CLK_DIV + 2) |
  *                     +---------------------------------------------+
  *
  *                  In transfer mode and according to the SD Card standard, 
  *                  make sure that the SDIO_CK frequency doesn't exceed 25MHz
  *                  and 50MHz in High-speed mode switch.
  *                  To be able to use a frequency higher than 24MHz, you should
  *                  use the SDIO peripheral in bypass mode. Refer to the 
  *                  corresponding reference manual for more details.
  *
  *              4 -  Select the corresponding SD Card according to the address
  *                   read with the step 2.
  *
  *              5 -  Configure the SD Card in wide bus mode: 4-bits data.
  *
  *          B - SD Card Read operation
  *          ========================== 
  *           - You can read SD card by using two functions : SD_ReadBlock() and
  *             SD_ReadMultiBlocks() functions. These functions support only
  *             512-byte block length.
  *           - The SD_ReadBlock() function reads only one block (512-byte). This
  *             function can transfer the data using DMA controller or using 
  *             polling mode. To select between DMA or polling mode refer to 
  *             "SD_DMA_MODE" or "SD_POLLING_MODE" inside the stm324x9i_eval_sdio_sd.h
  *             file and uncomment the corresponding line. By default the SD DMA
  *             mode is selected          
  *           - The SD_ReadMultiBlocks() function reads only mutli blocks (multiple 
  *             of 512-byte). 
  *           - Any read operation should be followed by two functions to check
  *             if the DMA Controller and SD Card status.
  *              - SD_ReadWaitOperation(): this function insure that the DMA
  *                controller has finished all data transfer.
  *              - SD_GetStatus(): to check that the SD Card has finished the 
  *                data transfer and it is ready for data.
  *
  *           - The DMA transfer is finished by the SDIO Data End interrupt. 
  *             User has to call the SD_ProcessIRQ() function inside the SDIO_IRQHandler()
  *             and SD_ProcessDMAIRQ() function inside the DMA2_Streamx_IRQHandler().
  *             Don't forget to enable the SDIO_IRQn and DMA2_Stream3_IRQn or 
  *             DMA2_Stream6_IRQn interrupts using the NVIC controller.
  *
  *          C - SD Card Write operation
  *          =========================== 
  *           - You can write SD card by using two function: SD_WriteBlock() and
  *             SD_WriteMultiBlocks() functions. These functions support only
  *             512-byte block length.   
  *           - The SD_WriteBlock() function write only one block (512-byte). This
  *             function can transfer the data using DMA controller or using 
  *             polling mode. To select between DMA or polling mode refer to 
  *             "SD_DMA_MODE" or "SD_POLLING_MODE" inside the stm324x9i_eval_sdio_sd.h
  *             file and uncomment the corresponding line. By default the SD DMA
  *             mode is selected          
  *           - The SD_WriteMultiBlocks() function write only mutli blocks (multiple 
  *             of 512-byte). 
  *           - Any write operation should be followed by two functions to check
  *             if the DMA Controller and SD Card status.
  *              - SD_ReadWaitOperation(): this function insure that the DMA
  *                controller has finished all data transfer.
  *              - SD_GetStatus(): to check that the SD Card has finished the 
  *                data transfer and it is ready for data.
  *
  *           - The DMA transfer is finished by the SDIO Data End interrupt. 
  *             User has to call the SD_ProcessIRQ() function inside the SDIO_IRQHandler()
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

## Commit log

2020-05-03 v1 PCB Layout
    [DigitalStethoscope.brd, DigitalStethoscope.sch]
2020-05-18 V1 PCB
2020-08-26 USB Audio Class dataIn from ADC

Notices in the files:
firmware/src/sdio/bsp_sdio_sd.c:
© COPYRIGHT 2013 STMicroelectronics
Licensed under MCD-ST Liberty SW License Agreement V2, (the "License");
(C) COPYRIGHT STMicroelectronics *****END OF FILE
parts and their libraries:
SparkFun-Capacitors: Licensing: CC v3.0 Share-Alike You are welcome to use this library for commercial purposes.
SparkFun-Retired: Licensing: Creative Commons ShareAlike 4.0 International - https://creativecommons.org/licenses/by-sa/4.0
